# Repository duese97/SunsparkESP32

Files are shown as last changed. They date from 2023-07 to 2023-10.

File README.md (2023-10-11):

# SunsparkESP32
A new ESP32 hardware platform for low power applications.

This PCB utilizes a small solar cell in order to harvest energy and store it in a supercapacitor.

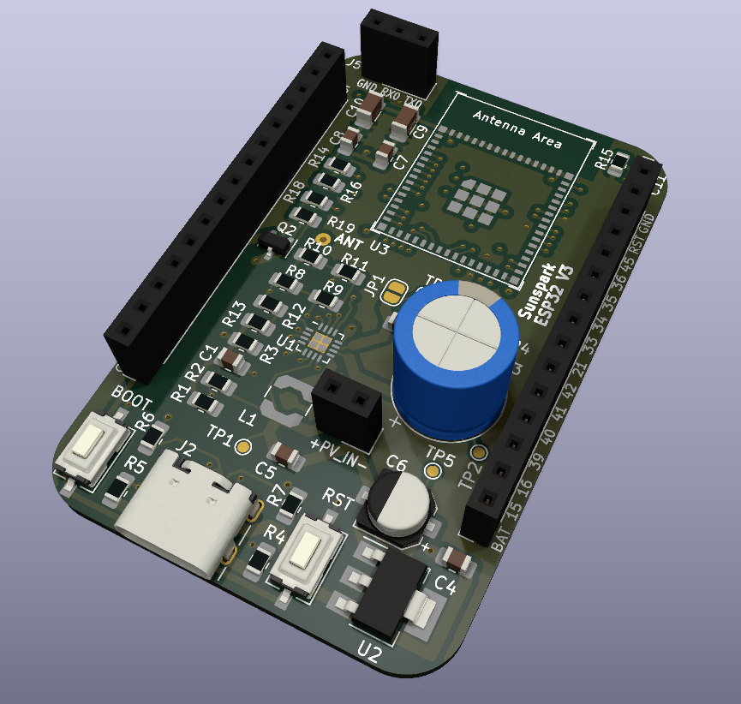
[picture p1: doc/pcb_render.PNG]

*The rendered PCB for the SunsparkESP32*

## Features
1. ESP32 S2 Mini module with a single core MCU: Most projects utilize one core anyway or don't benefit much form a second one. So no current is wasted by idling unnecessary.
2. Native USB support: Converter for RS232 can be connected externally. Many USB to RS232 transceivers have a high quiescent consumption. They are mostly needed for debugging, in order to show data to a console. Flashing the chip also works via the USB bootloader (and is also faster).
3. Integrated open drain MOSFET: Control high power external peripherals and turn them off when not needed.
4. VBUS from USB utilized automatically as backup supply, so debugging does not drain the supercap.
5. Optional RF95/96/97/98 LoRa module can be added (library used: https://github.com/sandeepmistry/arduino-LoRa/tree/master)

## Application example
I included some FW which realizes a simple WiFI weather station with a common BME280. However it can be easily altered to work with different or more sensors as well. It works well enough that it can sustain it's 10min scheduled data delivery indoors, in my living room.

Shutting down/entering deepsleep immediately after sending the UDP packet seems not to work (underlying RTOS or network stack takes some time). Thus I additionally set up the the UDP Server in a way that it sends a small sting back, upon receiving data.
The provided code does not utilizes this any further, but it could be a nice way for a two way communication. The ESP32 will run 1s at most, an then enter sleep again:
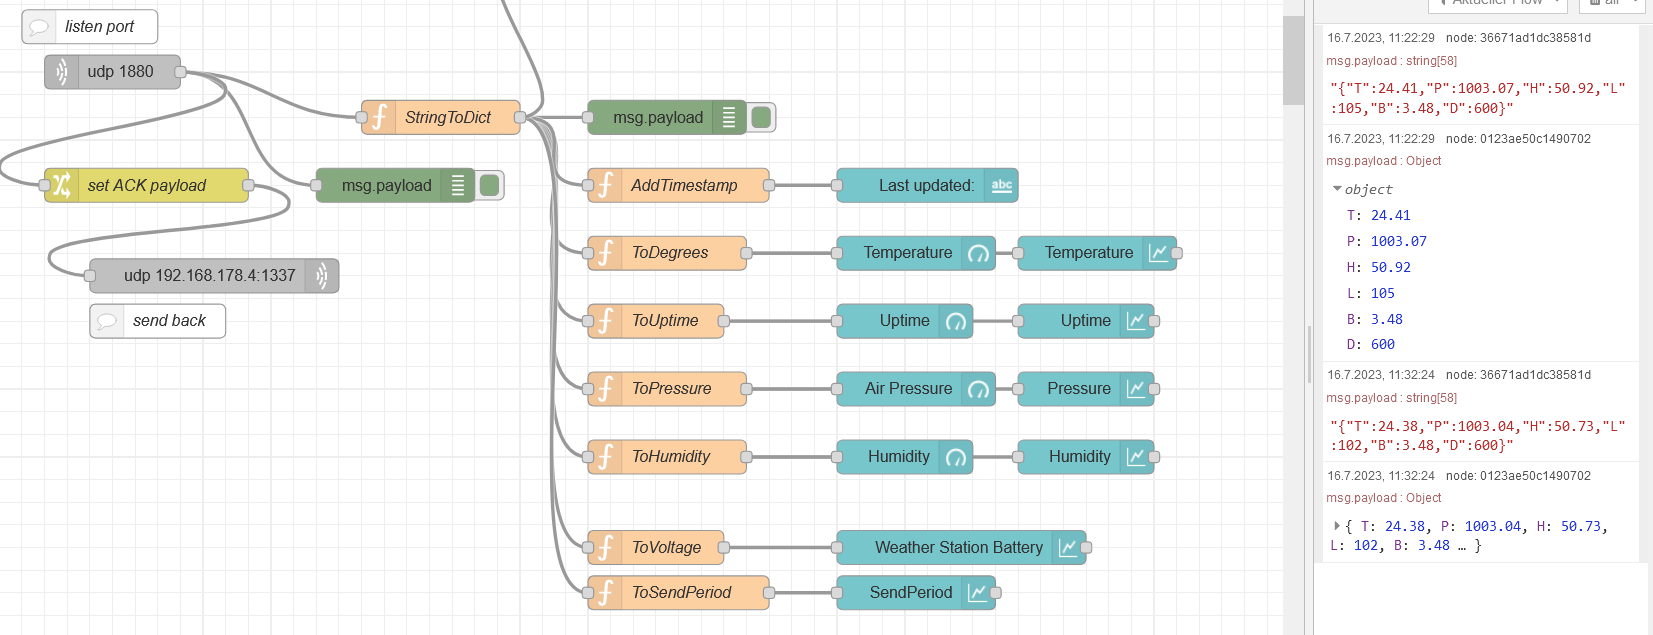
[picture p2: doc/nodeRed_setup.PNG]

*Example flow for parsing incoming results in Node RED*

There is also some small logic, which handles a depletion (or charging) of the supercap by altering the deepsleep period.

I found it helpful to include a runtime checked "debug mode". Tieing a GPIO to high, and to "artificially" shorten the sleep time, so I can debug more easily. Setting it to low put it back into "normal" mode and also disabled some UART prints.

Note: Altered Adafruit_BME280::begin so that is does NOT call
Adafruit_BME280::init upon each wakeup of device -> sensor is permanently
supplied with VCC and does not need a lengthy re-init each time

## Requirements for external components/assembly
1. The open circuit voltage of the solar cell should not exceed 3.3V. Recommended is 1.5V @ 0.65W
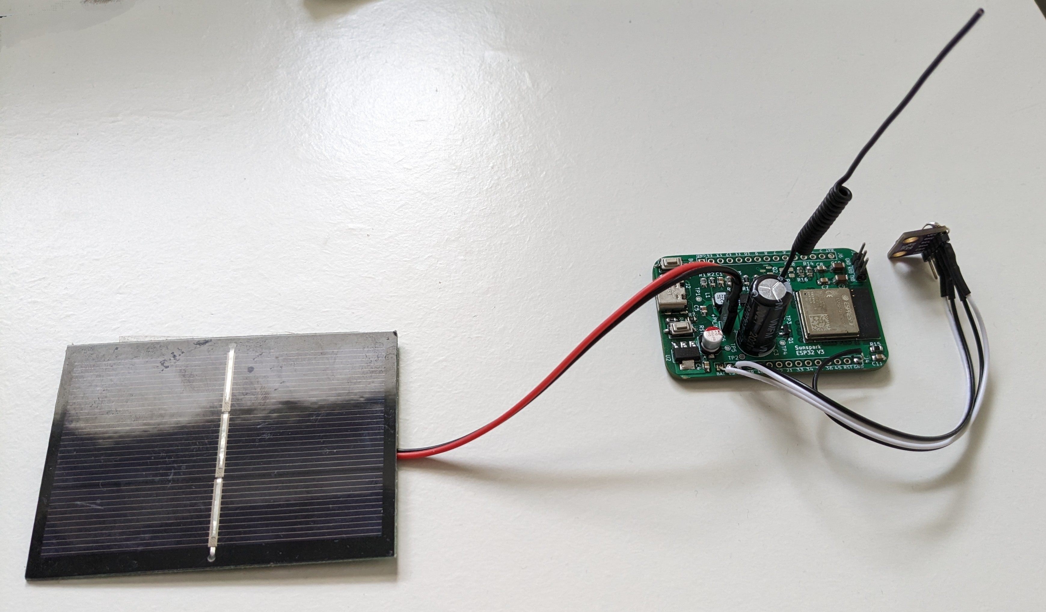
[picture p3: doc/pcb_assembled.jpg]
2. Make sure to protect the PCB when using it outdoors. Especially the Mega Ohm resistors are sensitive to water. I use clear nail polish for this. 
*The PCB with the solar cell and a BME280 soldered to it. The 433MHz antenna for the RF96 is also visible.*
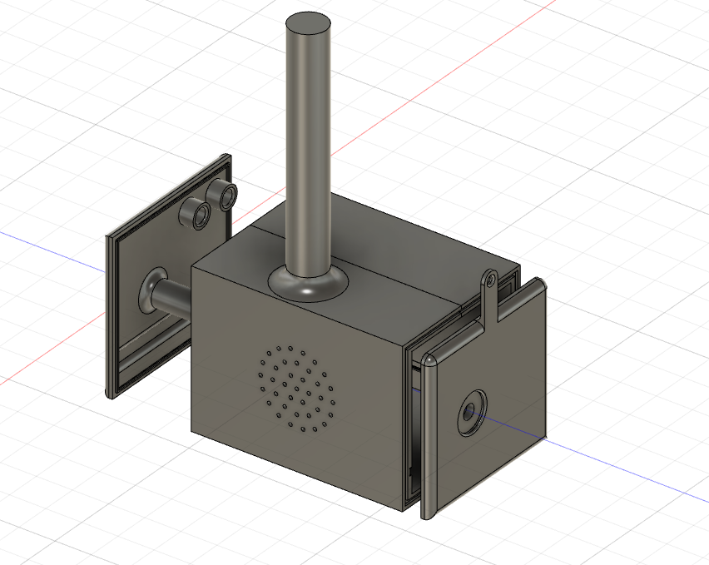
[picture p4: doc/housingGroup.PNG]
3. Mechanically a 3D printed assembly can accommodate the circuit shown above. The solar cell can be glued to the housing. 
*The 3D printed enclosure.*

## Errata
### V3 board
1. Current consumption with LoRa module seems too high in idle (when in deepsleep)
2. Still issues with occasional brownouts, when using WiFi
### V2 board
1. ~~USB VCOM for bootloader not working -> GND from USB and GND1 from ESP differ?~~ Forgot to compile with USB CDC enabled
2. BOOT button only working when Supercap is sufficiently charged?
3. Linear 3V3 regulator instantly produced some magic smoke upon connecting VBUS from USB :) There seem to be different pinouts for the same footprint of the same IC!
4. VREF for ADP5090 is too low and not constant

## Charging estimation
### V2 board
In direct sunlight: ~40mA, in the shade with average cloudiness: 2mA.

## Current consumption estimation
General testing consists of the board being flashed with a WiFi UDP client. It posts ~50B of data every 10 minutes to a Node RED UDP server. Static IP config is utilized, to avoid waiting for the DHCP.
Active time is about 0.5s, while sleeping the rest of the time.
The challenge are the short current bursts when the WiFi peripheral is actively used:
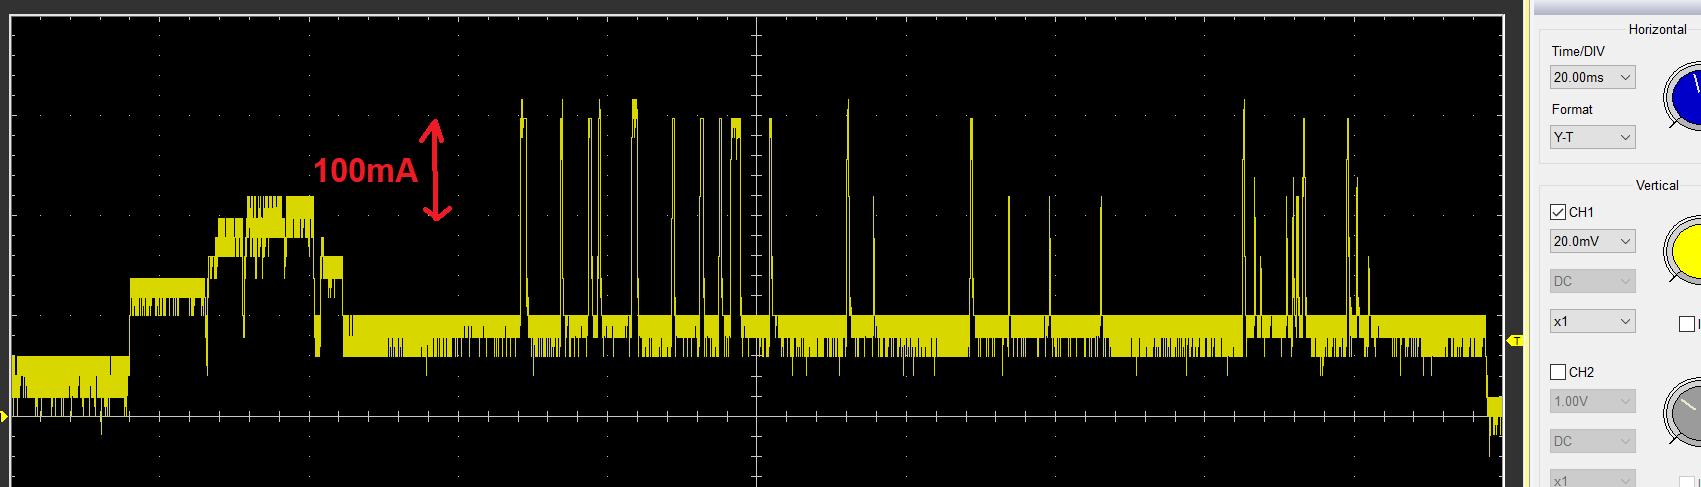
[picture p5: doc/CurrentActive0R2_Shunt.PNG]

*Scoped voltage over a shunt during board activity*

Values for estimating discharging of capacitor:
### V2 board
Active: 45mA; Sleep: 10µA; 50µA average

Improvements mostly due to better ceramic caps (?)
### V1 board
Active: 30mA; Sleep: 90µA; 115µA average

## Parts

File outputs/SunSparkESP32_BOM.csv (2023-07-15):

Id | Designator | Footprint | Quantity | Designation | Manufacturer | Comment | Mouser #
1 | C5,C2 | C_0805_2012Metric_Pad1.18x1.45mm_HandSolder | 2 | 4µ7 | C2012X5R1C475M085AB | low ESR, Generic 0805 | 810-C2012X5R1C475M0B
2 | L1 | L_Coilcraft_LPS4018 | 1 | 22µ | LPS4018-223MRC |  | 994-LPS4018-223MRC
3 | U1 | LFCSP-16-1EP_3x3mm_P0.5mm_EP1.7x1.7mm | 1 | ADP5090ACP | ADP5090ACPZ-2-R7 |  | 584-ADP5090ACPZ-2-R7
4 | R18,R19,R3,R14,R16 | R_0805_2012Metric_Pad1.20x1.40mm_HandSolder | 5 | 20k |  | Generic 0805
5 | C4,C1 | C_0805_2012Metric_Pad1.18x1.45mm_HandSolder | 2 | 10n | C0805X103K2RAC3316 | low ESR and leakage type | 80-C0805X103K2R3316
6 | R6,R7 | R_0805_2012Metric_Pad1.20x1.40mm_HandSolder | 2 | 22R |  | Generic 0805
7 | R12,R11 | R_0805_2012Metric_Pad1.20x1.40mm_HandSolder | 2 | 3.92M |  | Generic 0805
8 | C6 | CP_Elec_5x3 | 1 | 47µ | 865080242004 |  | 710-865080242004
9 | TP5,TP3,TP4,TP2,TP1 | TestPoint_Pad_D1.0mm | 5 | TestPoint
10 | R9 | R_0805_2012Metric_Pad1.20x1.40mm_HandSolder | 1 | 5.23M |  | Generic 0805
11 | C8,C11,C7 | C_0805_2012Metric_Pad1.18x1.45mm_HandSolder | 3 | 100n |  | Generic 0805
12 | R8 | R_0805_2012Metric_Pad1.20x1.40mm_HandSolder | 1 | 4.87M |  | Generic 0805
13 | U3 | ESP32-S2-MINI-1 | 1 | ESP32-S2-MINI-1 | ESP32-S2-MINI-1-N4 |  | 356-ESP32-S2-MINI-1
14 | SW2,SW1 | SW_Tactile_SPST_NO_Straight_CK_PTS636Sx25SMTRLFS | 2 | SW_Push | PTS636 SM25J SMTR LFS |  | 611-PTS636SM25JSMTRL
15 | R15 | R_0805_2012Metric_Pad1.20x1.40mm_HandSolder | 1 | 10k |  | Generic 0805
16 | J2 | USB_C_Receptacle_GCT_USB4105-xx-A_16P_TopMnt_Horizontal | 1 | USB_C_Receptacle_USB2.0 | USB4105-GF-A |  | 640-USB4105-GF-A
17 | J5 | PinSocket_1x03_P2.54mm_Vertical | 1 | Conn_01x03_Pin |  | generic pin header
18 | R5,R4 | R_0805_2012Metric_Pad1.20x1.40mm_HandSolder | 2 | 5.1k |  | Generic 0805
19 | Q1,Q2 | SOT-23 | 2 | IRLML6244TRPBF | IRLML6244TRPBF |  | 942-IRLML6244TRPBF
20 | C9,C10 | C_1206_3216Metric | 2 | 22µ | C3216JB1C226M160AB | low ESR | 810-C3216JB1C226M16B
21 | JP1,JP2 | SolderJumper-2_P1.3mm_Open_RoundedPad1.0x1.5mm | 2 | SolderJumper_2_Open
22 | R1 | R_0805_2012Metric_Pad1.20x1.40mm_HandSolder | 1 | 13M |  | Generic 0805
23 | J1 | PinSocket_1x02_P2.54mm_Vertical | 1 | Conn_01x02_Pin |  | generic pin header
24 | R10,R13 | R_0805_2012Metric_Pad1.20x1.40mm_HandSolder | 2 | 6.04M |  | Generic 0805
25 | J4,J6 | PinSocket_1x15_P2.54mm_Vertical | 2 | Conn_01x15_Pin |  | generic pin header
26 | U2 | SOT-223-3_TabPin2 | 1 | AMS1117-3.3 | TLV1117LV33DCYT | Watch for variants with different pinning, not any generic 1117 will work!!! | 595-TLV1117LV33DCYT
27 | C3 | CP_Radial_D10.0mm_P5.00mm | 1 | 50F | VMF506M3R8 | Must tolerate 3.6V, 30..50F is ok | 598-VMF506M3R8
28 | R2 | R_0805_2012Metric_Pad1.20x1.40mm_HandSolder | 1 | 6.34M |  | Generic 0805
29 | J7 | TestPoint_THTPad_D1.5mm_Drill0.7mm | 1 | Conn_01x01_Pin |  | generic pin header
30 | U4 | HOPERF_RFM9XW_SMD | 1 | RFM96W-433S2

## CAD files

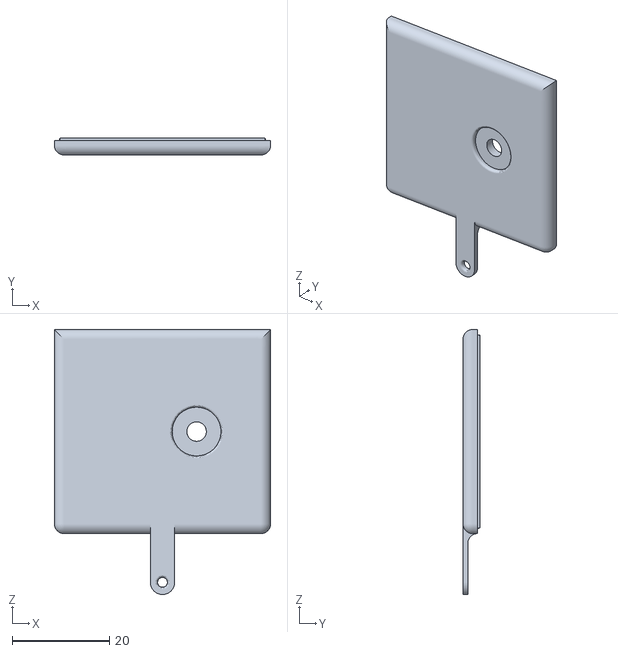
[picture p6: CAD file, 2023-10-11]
mechanical/lid_small.stl
44.4 x 3.50 x 54.4

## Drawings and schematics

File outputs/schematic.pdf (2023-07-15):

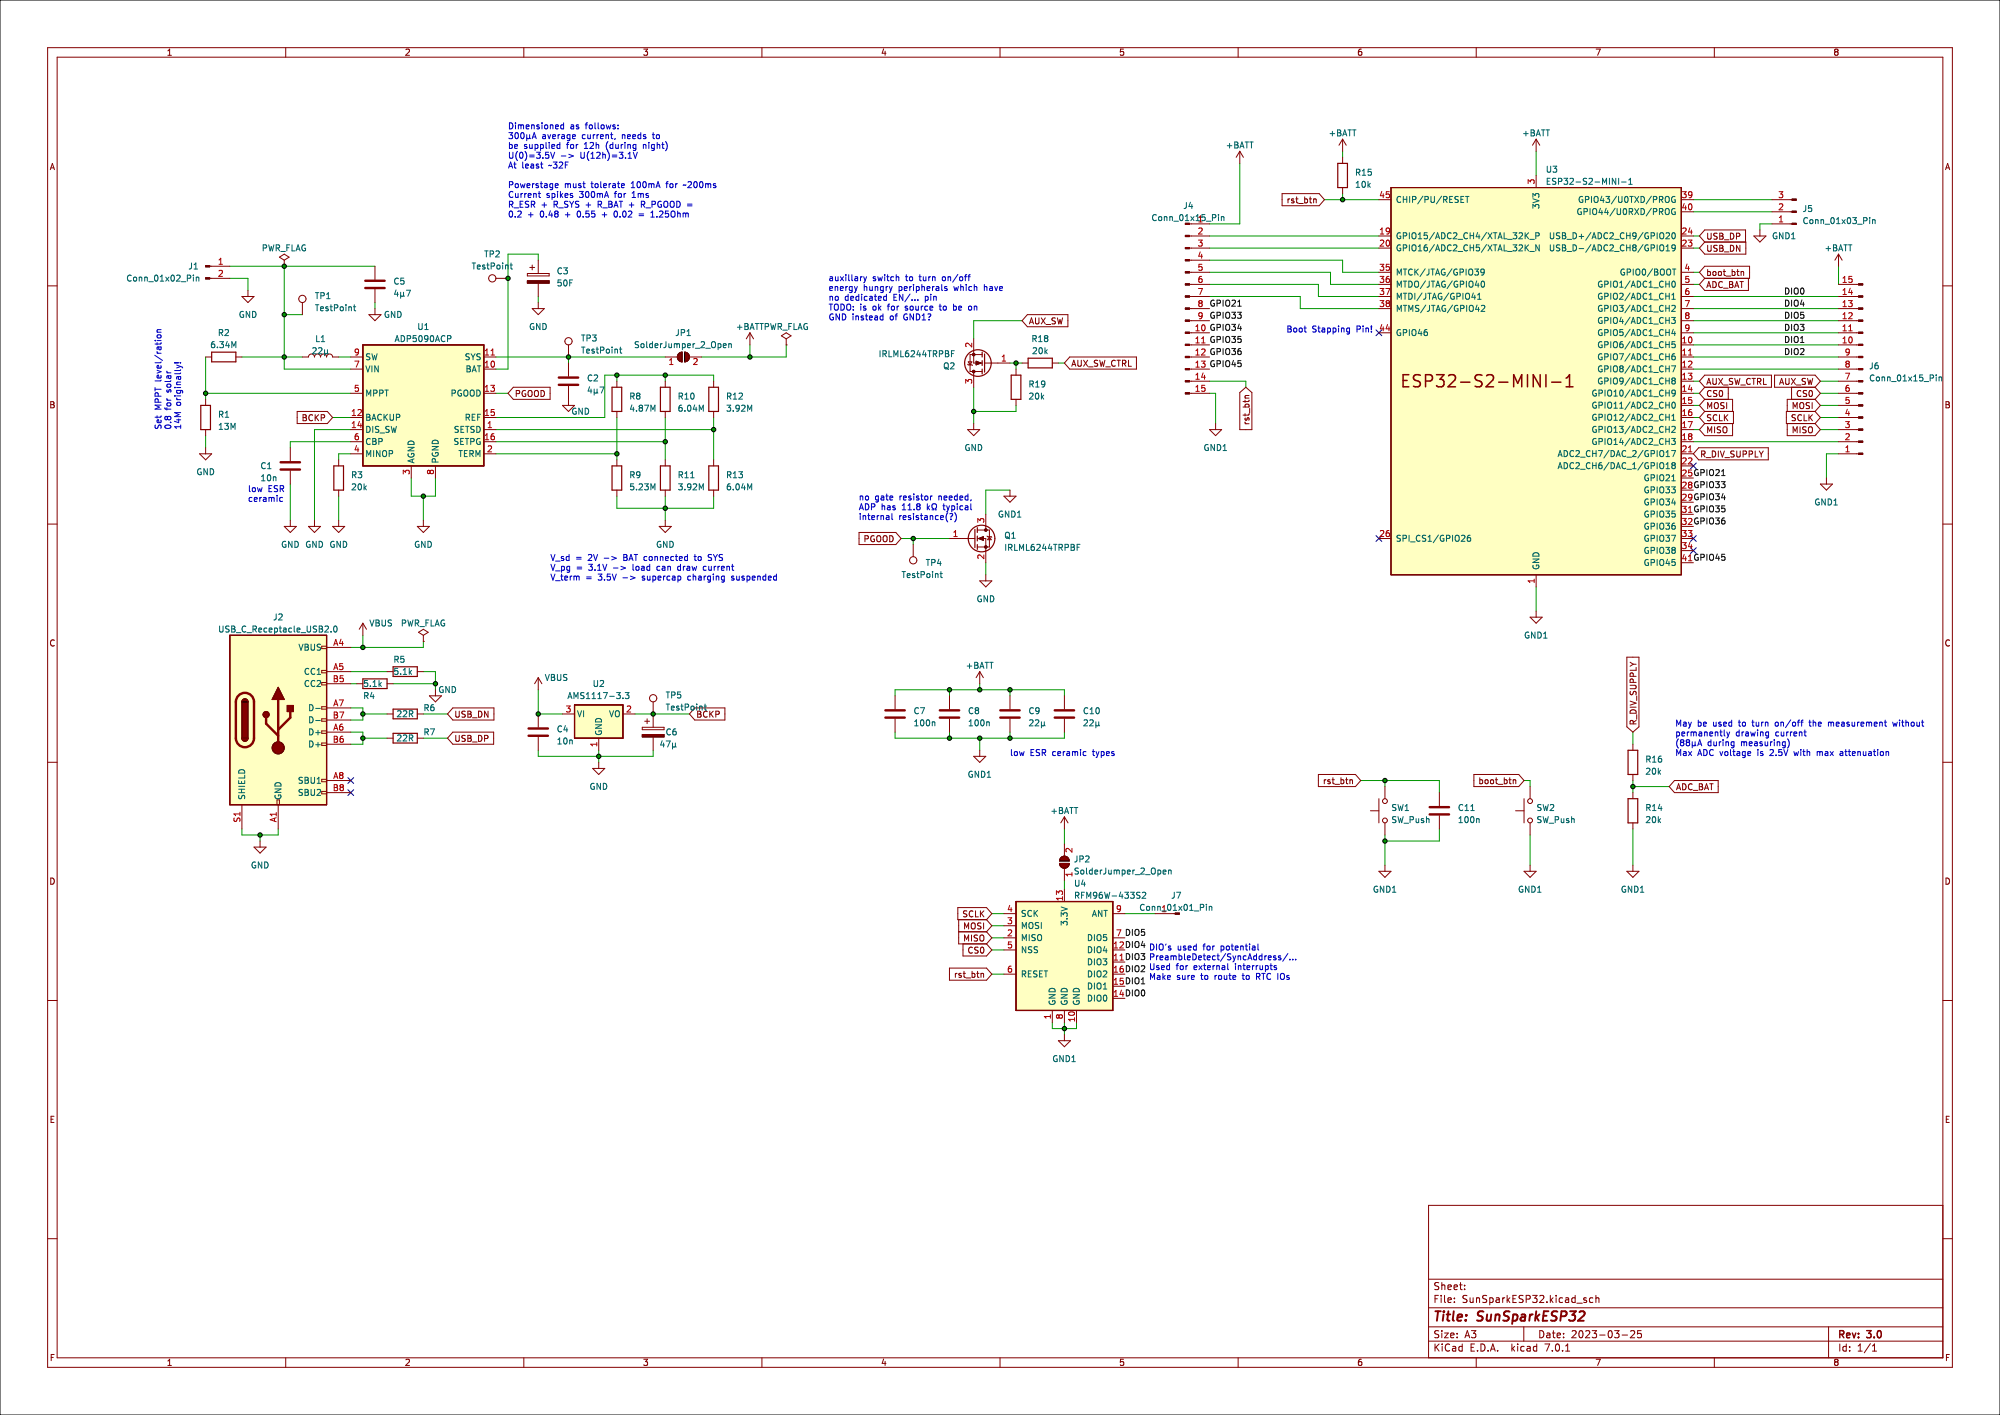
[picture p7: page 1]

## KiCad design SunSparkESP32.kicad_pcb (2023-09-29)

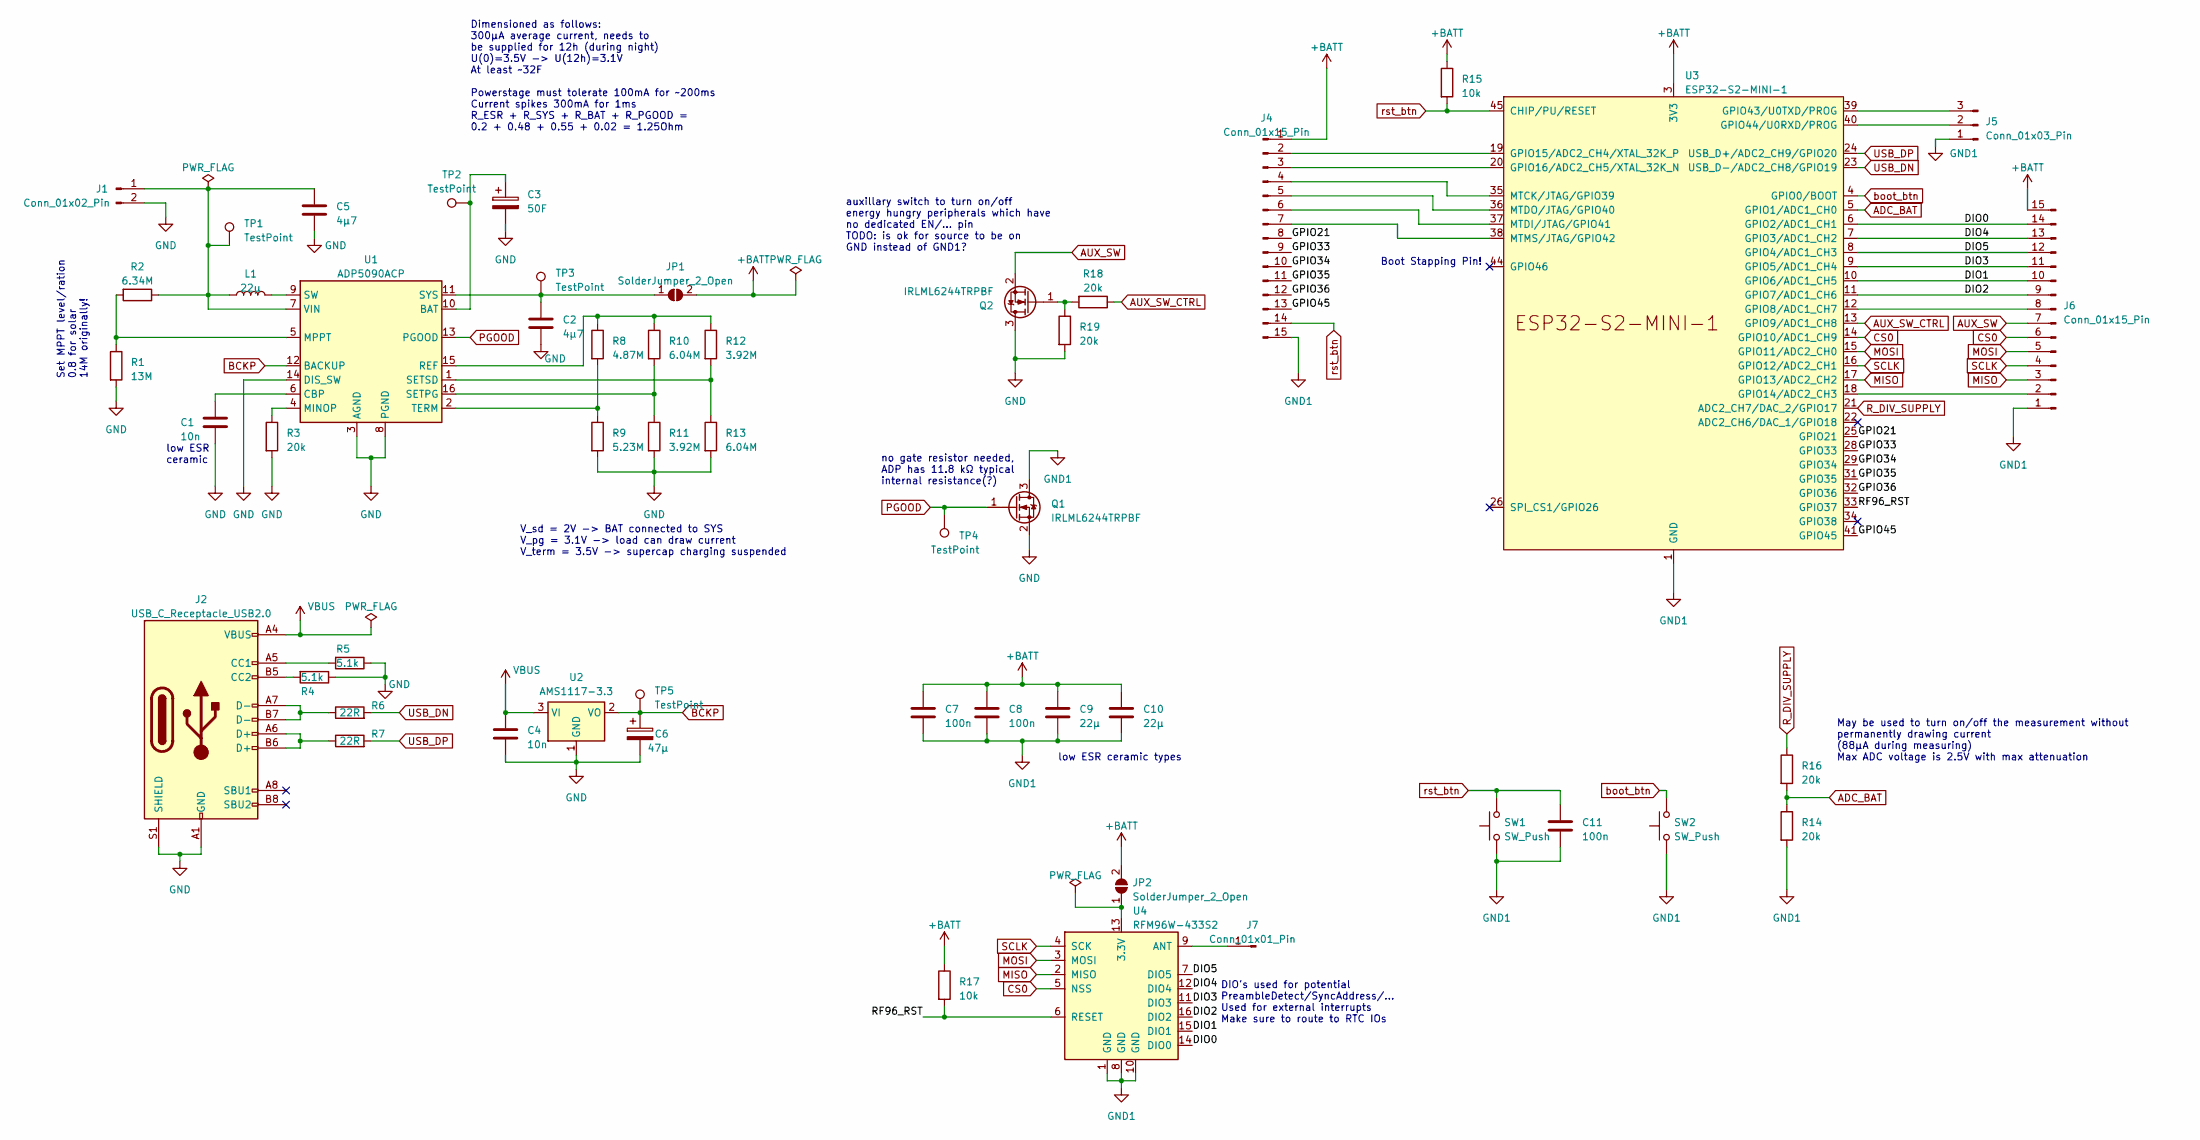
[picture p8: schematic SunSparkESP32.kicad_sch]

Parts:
C1, C4: 10n; C_0805_2012Metric_Pad1.18x1.45mm_HandSolder
C2, C5: 4µ7; C_0805_2012Metric_Pad1.18x1.45mm_HandSolder
C3: 50F; CP_Radial_D10.0mm_P5.00mm
C6: 47µ; CP_Elec_5x3
C7, C8, C11: 100n; C_0805_2012Metric_Pad1.18x1.45mm_HandSolder
C9, C10: 22µ; C_1206_3216Metric
J1: Conn_01x02_Pin; PinSocket_1x02_P2.54mm_Vertical
J2: USB_C_Receptacle_USB2.0; USB_C_Receptacle_GCT_USB4105-xx-A_16P_TopMnt_Horizontal
J4, J6: Conn_01x15_Pin; PinSocket_1x15_P2.54mm_Vertical
J5: Conn_01x03_Pin; PinSocket_1x03_P2.54mm_Vertical
J7: Conn_01x01_Pin; TestPoint_THTPad_D1.5mm_Drill0.7mm
JP1, JP2: SolderJumper_2_Open; SolderJumper-2_P1.3mm_Open_RoundedPad1.0x1.5mm
L1: 22µ; L_Coilcraft_LPS4018
Q1, Q2: IRLML6244TRPBF; SOT-23
R1: 13M; R_0805_2012Metric_Pad1.20x1.40mm_HandSolder
R2: 6.34M; R_0805_2012Metric_Pad1.20x1.40mm_HandSolder
R3, R14, R16, R18, R19: 20k; R_0805_2012Metric_Pad1.20x1.40mm_HandSolder
R4, R5: 5.1k; R_0805_2012Metric_Pad1.20x1.40mm_HandSolder
R6, R7: 22R; R_0805_2012Metric_Pad1.20x1.40mm_HandSolder
R8: 4.87M; R_0805_2012Metric_Pad1.20x1.40mm_HandSolder
R9: 5.23M; R_0805_2012Metric_Pad1.20x1.40mm_HandSolder
R10, R13: 6.04M; R_0805_2012Metric_Pad1.20x1.40mm_HandSolder
R11, R12: 3.92M; R_0805_2012Metric_Pad1.20x1.40mm_HandSolder
R15, R17: 10k; R_0805_2012Metric_Pad1.20x1.40mm_HandSolder
SW1, SW2: SW_Push; SW_Tactile_SPST_NO_Straight_CK_PTS636Sx25SMTRLFS
TP1, TP2, TP3, TP4, TP5: TestPoint; TestPoint_Pad_D1.0mm
U1: ADP5090ACP; LFCSP-16-1EP_3x3mm_P0.5mm_EP1.7x1.7mm
U2: AMS1117-3.3; SOT-223-3_TabPin2
U3: ESP32-S2-MINI-1
U4: RFM96W-433S2; HOPERF_RFM9XW_SMD

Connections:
+BATT: C7.1, C8.1, C9.1, C10.1, J4.1, J6.15, JP1.2 (B), JP2.2 (B), R15.1, R17.1, U3.3 (3V3)
/DIO0: J6.14, U3.6 (GPIO2/ADC1_CH1), U4.14 (DIO0)
/DIO1: J6.10, U3.10 (GPIO6/ADC1_CH5), U4.15 (DIO1)
/DIO2: J6.9, U3.11 (GPIO7/ADC1_CH6), U4.16 (DIO2)
/DIO3: J6.11, U3.9 (GPIO5/ADC1_CH4), U4.11 (DIO3)
/DIO4: J6.13, U3.7 (GPIO3/ADC1_CH2), U4.12 (DIO4)
/DIO5: J6.12, U3.8 (GPIO4/ADC1_CH3), U4.7 (DIO5)
/GPIO21: J4.8, U3.25 (GPIO21)
/GPIO33: J4.9, U3.28 (GPIO33)
/GPIO34: J4.10, U3.29 (GPIO34)
/GPIO35: J4.11, U3.31 (GPIO35)
/GPIO36: J4.12, U3.32 (GPIO36)
/GPIO45: J4.13, U3.41 (GPIO45)
/RF96_RST: R17.2, U3.33 (GPIO37), U4.6 (RESET)
ADC_BAT: R14.1, R16.2, U3.5 (GPIO1/ADC1_CH0)
AUX_SW: J6.7, Q2.2 (S)
AUX_SW_CTRL: R18.1, U3.13 (GPIO9/ADC1_CH8)
BCKP: C6.1, TP5.1, U1.12 (BACKUP), U2.2 (VO)
CS0: J6.6, U3.14 (GPIO10/ADC1_CH9), U4.5 (NSS)
GND: C1.2, C2.2, C3.2, C4.2, C5.2, C6.2, J1.2, J2.A1 (GND), J2.A12 (GND), J2.B1 (GND), J2.B12 (GND), J2.S1 (SHIELD), Q1.2 (S), Q2.3 (D), R1.2, R3.2, R4.1, R5.1, R9.2, R11.2, R13.2, R19.2, U1.3 (AGND), U1.8 (PGND), U1.14 (DIS_SW), U1.17 (AGND), U2.1 (GND)
GND1: C7.2, C8.2, C9.2, C10.2, C11.2, J4.15, J5.1, J6.1, Q1.3 (D), R14.2, SW1.1, SW2.1, U3.1 (GND), U3.2 (GND), U3.30 (GND), U3.42 (GND), U3.43 (GND), U3.46 (GND), U3.47 (GND), U3.48 (GND), U3.49 (GND), U3.50 (GND), U3.51 (GND), U3.52 (GND), U3.53 (GND), U3.54 (GND), U3.55 (GND), U3.56 (GND), U3.57 (GND), U3.58 (GND), U3.59 (GND), U3.60 (GND), U3.61 (GND), U3.62 (GND), U3.63 (GND), U3.64 (GND), U3.65 (GND), U4.1 (GND), U4.8 (GND), U4.10 (GND)
MISO: J6.3, U3.17 (GPIO13/ADC2_CH2), U4.2 (MISO)
MOSI: J6.5, U3.15 (GPIO11/ADC2_CH0), U4.3 (MOSI)
unnamed: C5.1, J1.1, L1.1, R2.1, TP1.1, U1.7 (VIN)
unnamed: J2.A5 (CC1), R5.2
unnamed: J2.B5 (CC2), R4.2
unnamed: J2.A6 (D+), J2.B6 (D+), R7.1
unnamed: J2.A7 (D-), J2.B7 (D-), R6.1
unnamed: J4.2, U3.19 (GPIO15/ADC2_CH4/XTAL_32K_P)
unnamed: J4.3, U3.20 (GPIO16/ADC2_CH5/XTAL_32K_N)
unnamed: J4.4, U3.35 (MTCK/JTAG/GPIO39)
unnamed: J4.5, U3.36 (MTDO/JTAG/GPIO40)
unnamed: J4.6, U3.37 (MTDI/JTAG/GPIO41)
unnamed: J4.7, U3.38 (MTMS/JTAG/GPIO42)
unnamed: J5.2, U3.40 (GPIO44/U0RXD/PROG)
unnamed: J5.3, U3.39 (GPIO43/U0TXD/PROG)
unnamed: J6.2, U3.18 (GPIO14/ADC2_CH3)
unnamed: J6.8, U3.12 (GPIO8/ADC1_CH7)
unnamed: J7.1, U4.9 (ANT)
unnamed: C2.1, JP1.1 (A), TP3.1, U1.11 (SYS)
unnamed: JP2.1 (A), U4.13 (3.3V)
unnamed: Q2.1 (G), R18.2, R19.1
unnamed: C3.1, TP2.1, U1.10 (BAT)
unnamed: C1.1, U1.6 (CBP)
unnamed: R3.1, U1.4 (MINOP)
unnamed: R1.1, R2.2, U1.5 (MPPT)
unnamed: R8.1, R10.1, R12.1, U1.15 (REF)
unnamed: R10.2, R11.1, U1.16 (SETPG)
unnamed: R12.2, R13.1, U1.1 (SETSD)
unnamed: L1.2, U1.9 (SW)
unnamed: R8.2, R9.1, U1.2 (TERM)
PGOOD: Q1.1 (G), TP4.1, U1.13 (PGOOD)
R_DIV_SUPPLY: R16.1, U3.21 (ADC2_CH7/DAC_2/GPIO17)
SCLK: J6.4, U3.16 (GPIO12/ADC2_CH1), U4.4 (SCK)
USB_DN: R6.2, U3.23 (USB_D-/ADC2_CH8/GPIO19)
USB_DP: R7.2, U3.24 (USB_D+/ADC2_CH9/GPIO20)
VBUS: C4.1, J2.A4 (VBUS), J2.A9 (VBUS), J2.B4 (VBUS), J2.B9 (VBUS), U2.3 (VI)
boot_btn: SW2.2, U3.4 (GPIO0/BOOT)
rst_btn: C11.1, J4.14, R15.2, SW1.2, U3.45 (CHIP/PU/RESET)

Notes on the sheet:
Set MPPT level/ration 0.8 for solar 14M originally!
no gate resistor needed, ADP has 11.8 kΩ typical internal resistance(?)
low ESR ceramic types
Dimensioned as follows: 300µA average current, needs to be supplied for 12h (during night) U(0)=3.5V -> U(12h)=3.1V At least ~32F Powerstage must tolerate 100mA for ~200ms Current spikes 300mA for 1ms R_ESR + R_SYS + R_BAT + R_PGOOD = 0.2 + 0.48 + 0.55 + 0.02 = 1.25Ohm
low ESR ceramic
May be used to turn on/off the measurement without permanently drawing current (88µA during measuring) Max ADC voltage is 2.5V with max attenuation
V_sd = 2V -> BAT connected to SYS V_pg = 3.1V -> load can draw current V_term = 3.5V -> supercap charging suspended
auxillary switch to turn on/off energy hungry peripherals which have no dedicated EN/... pin TODO: is ok for source to be on GND instead of GND1?
DIO's used for potential PreambleDetect/SyncAddress/... Used for external interrupts Make sure to route to RTC IOs
Boot Stapping Pin!

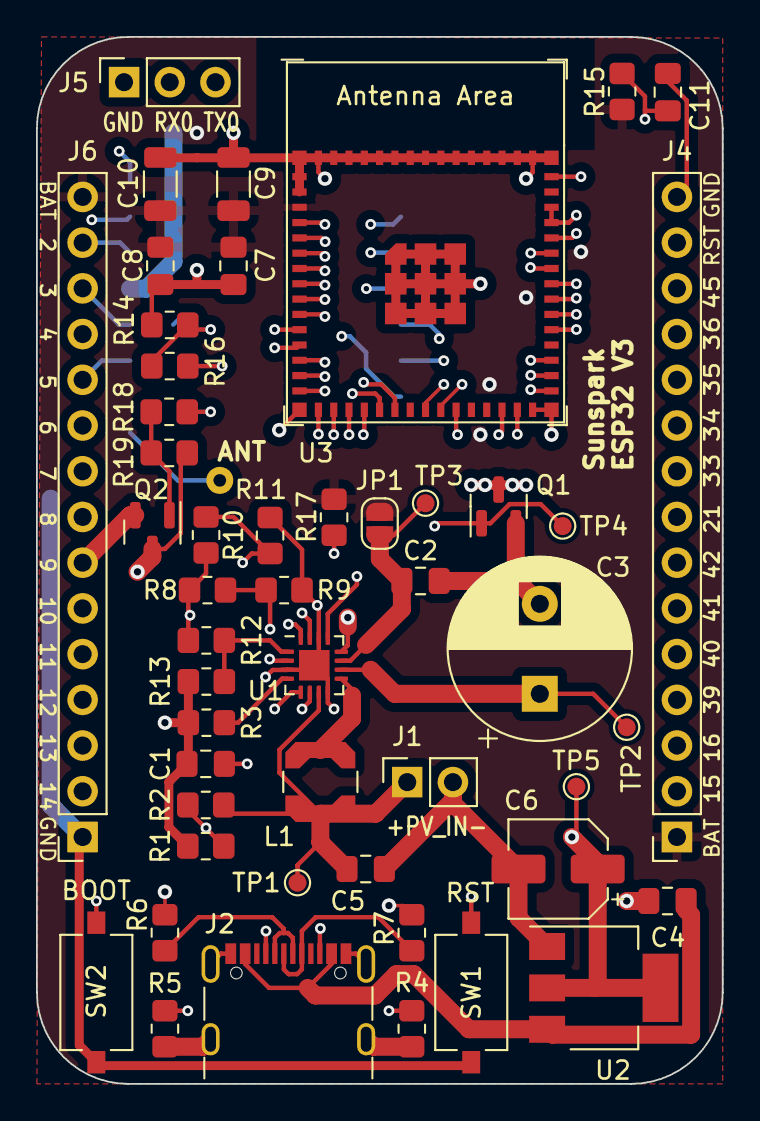
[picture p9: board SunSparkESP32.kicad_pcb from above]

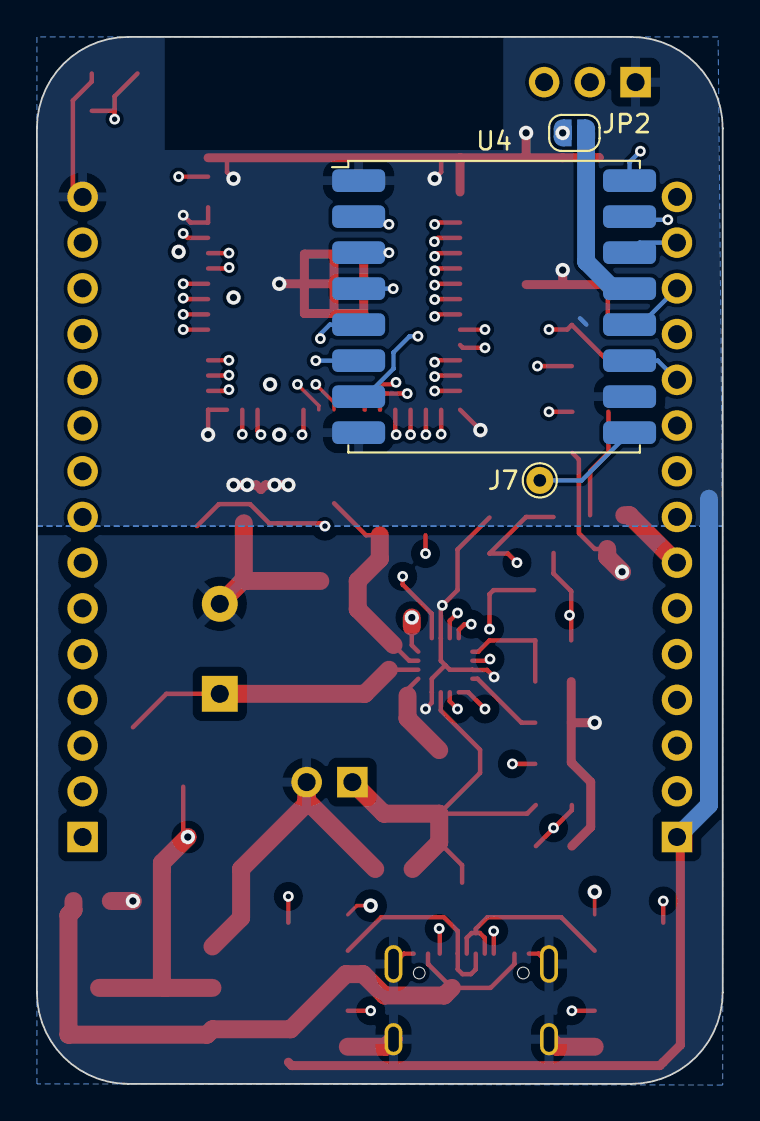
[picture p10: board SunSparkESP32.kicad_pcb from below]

Board: 4 copper layers, 38.1 x 58.2 mm, 52 parts (3 on the bottom side), 59 nets.

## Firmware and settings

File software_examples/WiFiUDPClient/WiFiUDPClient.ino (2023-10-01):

#include <Arduino.h>

#include <HardwareSerial.h>

#include <Wire.h>

/* SENSOR SPECIFIC INCLUDES */
#include <SPI.h>
#include <Adafruit_Sensor.h>
#include <Adafruit_BME280.h>

#include "esp32s2/rom/rtc.h"  // for reset reason etc.
#include "esp32/clk.h"

#define WIFI_USED 0

#if WIFI_USED == 1
#include <WiFi.h>
#include <WiFiUdp.h>
#else
#include <SPI.h>
#include <LoRa.h>
#endif  // WIFI_USED


/* Pins where UART pin header is routed */
#define RXD0 40
#define TXD0 39

#define DEBUG_PIN 40

#define RF96_DIO0 2
#define RF96_CS 10
#define RF96_MOSI 11
#define RF96_CLK 12
#define RF96_MISO 13

/* Conversion factors for time related stuff */
#define SECONDS_PER_MIN 60
#define MIN_PER_HOUR 60
#define uS_TO_S_FACTOR 1000000
#define mS_TO_S_FACTOR 1000

/* Constants which influence wakup and sleep behaviour */
#define MIN_SLEEP_TIME SECONDS_PER_MIN * 10               // Time ESP32 will go to sleep (in seconds)
#define MAX_SLEEP_TIME SECONDS_PER_MIN* MIN_PER_HOUR * 8  // sleep third a day at max
#define DEBUG_SLEEP_TIME SECONDS_PER_MIN                  // for quickly debugging
#define NETWORK_WAIT_MS 1                                 // task delay in polling loop
#define MAX_WAKEUP_MS 1000                                // total amount of milli seconds device operation can be done

/* Supercap related */
#define CAP_FULL_LVL 3.4    // if this or higher is read, then supercap is definetly full
#define CAP_NORMAL_LVL 3.3  // voltage threshold above which normal operation can take place
#define PIN_R_DIV 17        // pin which powers voltage divider for ADC
#define PIN_ADC 1           // where midpoint of divider is connected

// only need to use (and waste) ebergy when debugging
#define custom_println(...) \
  if (use_debug_mode) { \
    snprintf(print_buffer, sizeof(print_buffer), __VA_ARGS__); \
    customSerial.println(print_buffer); \
  }

/* values for statemachine */
enum {
  STATE_SENSOR_INIT,   // optional: in case sensor feature sleeping state as well, init can be skipped most of times
  STATE_SENSOR_READ,   // optional: do sensor readings before starting wifi transceiver!
  STATE_NETWORK_INIT,  // setting up wifi
  STATE_NETWORK_WAIT,  // waiting for intial connect
  STATE_SEND,          // transmitting data
  STATE_WAIT_ACK,      // optional: receive data back
  STATE_SLEEP,         // prepare sleeping
};

#if WIFI_USED == 1
/* Network related constants */
const char * networkName    = "your_ssid"; // name of wifi
const char * networkPswd    = "your_password";          // password of wifi

// set these up in router, so that ít conflicts with nothing else
const char* device_ip = "192.168.178.4";
const char* device_subnet = "255.255.255.0";
const char* device_gateway = "192.168.178.1";

const char* udpAddress = "192.168.178.33";  // IP address to send UDP data to
const int udpListenPort = 1337;             // on which port to listen
const int udpSendPort = 1880;               // to which port to send to

/* Network variables */
WiFiUDP Udp;  //The Udp library class
#endif        // WIFI_USED


/* State machine */
uint32_t millis_start, active_time;
RTC_DATA_ATTR uint32_t last_active;               // to measure entire cycle, can be outputted upon next connect
RTC_DATA_ATTR float last_delta_v;                 // to measure entire cycle, can be outputted upon next connect
volatile uint8_t curr_state = STATE_SENSOR_READ;  // default state, init only set if
bool use_debug_mode = false;                      // flag for easily debugging code via prints :)
bool lora_active = false;

float supercap_voltage;                                      // supercap voltage in V
RTC_DATA_ATTR uint32_t timeToSleepSeconds = MIN_SLEEP_TIME;  // sleep time, stored in RTC RAM to also take past operation into account


/* ADD SENSOR SPECIFIC CODE HERE */
#define BME_WAIT_MS 10
#define I2C_SDA 15
#define I2C_SCL 16

RTC_DATA_ATTR Adafruit_BME280 bme;  // I2C
float temp, humi, press;

/* Print buffer for easily formatting */
char print_buffer[256];

HardwareSerial customSerial(0);

#if WIFI_USED == 1
/* Wifi callbacks */
void connectToWiFi(const char* ssid, const char* pwd) {
  custom_println("Connecting to WiFi network: %s", ssid);

  // delete old config
  WiFi.disconnect(true);
  //register event handler
  WiFi.onEvent(WiFiEvent);

  // setup static config
  IPAddress localIP, gateway, subnet;
  localIP.fromString(device_ip);
  gateway.fromString(device_gateway);
  subnet.fromString(device_subnet);

  WiFi.config(localIP, gateway, subnet);

  //Initiate connection
  WiFi.begin(ssid, pwd);

  custom_println("Waiting for WIFI connection...");
}

//wifi event handler
void WiFiEvent(WiFiEvent_t event) {
  switch (event) {
    case ARDUINO_EVENT_WIFI_STA_GOT_IP:  //When connected set
      custom_println("WiFi connected! IP address: %s", WiFi.localIP().toString().c_str());

      //initializes the UDP state -> This initializes the transfer buffer
      Udp.begin(WiFi.localIP(), udpListenPort);
      curr_state = STATE_SEND;
      break;

    case ARDUINO_EVENT_WIFI_STA_DISCONNECTED:
      custom_println("WiFi lost connection");
      curr_state = STATE_NETWORK_WAIT;
      break;
    default:
      break;
  }
}
#endif

// wrapper enter deepsleep
static void enter_deepsleep(void) {
  custom_println("%s", "Entering sleep");
  last_active = active_time;
  uint64_t sleepUs = timeToSleepSeconds * uS_TO_S_FACTOR - active_time * mS_TO_S_FACTOR;

  // take delay due to active time into account, to compensate for runtime
  esp_sleep_enable_timer_wakeup(sleepUs);
  esp_sleep_pd_config(ESP_PD_DOMAIN_RTC_PERIPH, ESP_PD_OPTION_OFF);
  esp_deep_sleep_start();
}

static float measure_adc(void) {
  float value;

  pinMode(PIN_R_DIV, OUTPUT);  // use pin to briefly drive voltage divider
  digitalWrite(PIN_R_DIV, HIGH);

  analogSetAttenuation(ADC_11db);
  value = (analogReadMilliVolts(PIN_ADC) / 1000.0) * 2;  // read voltage, is double that what we read

  digitalWrite(PIN_R_DIV, LOW);  // reset output so no current is drawn anymore

  return value;
}

// determines next sleep period and stores it in RTC RAM
static void calc_next_sleep(void) {
  supercap_voltage = measure_adc();

  /* Logic to determine next wakeup, depending on supercap charge */
  if (use_debug_mode) {
    timeToSleepSeconds = DEBUG_SLEEP_TIME;
  } else if (supercap_voltage >= CAP_FULL_LVL) {
    // cap is full, no matter what previously happend, reset sleep period to min
    timeToSleepSeconds = MIN_SLEEP_TIME;
  } else if (supercap_voltage >= CAP_NORMAL_LVL) {
    // cap charge is recovering, half the used period
    timeToSleepSeconds /= 2;
    if (timeToSleepSeconds < MIN_SLEEP_TIME)  // watch out to not make it too small
    {
      timeToSleepSeconds = MIN_SLEEP_TIME;
    }
  } else if (timeToSleepSeconds < MAX_SLEEP_TIME) {
    // double sleep period to save more energy
    timeToSleepSeconds *= 2;
  } else  // we are already waiting with the maximum possible period
  {
    timeToSleepSeconds = MAX_SLEEP_TIME;  // make sure to reset it to a proper value
  }
  custom_println("Chose sleep period: %lds", timeToSleepSeconds);
}

void setup() {
  /* WiFI needs min 80MHz, don't need that much for LoRa */
#if WIFI_USED == 1
  setCpuFrequencyMhz(80E6);
#else
  setCpuFrequencyMhz(10E6);
#endif // WIFI_USED

  RESET_REASON reason = rtc_get_reset_reason(0);  // check why we woke up
  pinMode(DEBUG_PIN, INPUT_PULLDOWN);
  use_debug_mode = digitalRead(DEBUG_PIN);

  // Initialize hardware serial
  customSerial.begin(115200, SERIAL_8N1, RXD0, TXD0);
  custom_println("SunsparkESP32 start, reset reason: %d", reason);  // output reset reason

  switch (reason)  // depending on
  {
    case RTCWDT_BROWN_OUT_RESET:  // when brownout was active: don't continue, save energy
      enter_deepsleep();
      break;

    case POWERON_RESET:
      curr_state = STATE_SENSOR_INIT;

    default:  // will most ofen land here, rtc wakeup
      break;
  }

  calc_next_sleep();
  millis_start = millis();  // remember start of statemachine

  /* DO SENSOR SPECIFIC STUFF HERE */
  Wire.begin(I2C_SDA, I2C_SCL, 400000);
  bme.begin(0x76);
}

void loop() {
  do {
    active_time = millis() - millis_start;  // calculate wifi active time
    bool state_changed = false;

    switch (curr_state) {
      case STATE_SENSOR_INIT:
        if (bme.init())  // success
        {
          curr_state = STATE_SENSOR_READ;
          state_changed = true;

          custom_println("BME280 found");
          break;
        } else {
          custom_println("Retrying BME init...");
          vTaskDelay(BME_WAIT_MS);
        }
        break;

      case STATE_SENSOR_READ:
        bme.setSampling(Adafruit_BME280::MODE_FORCED,
                        Adafruit_BME280::SAMPLING_X1,  // temperature
                        Adafruit_BME280::SAMPLING_X1,  // pressure
                        Adafruit_BME280::SAMPLING_X1,  // humidity
                        Adafruit_BME280::FILTER_OFF);

        if (bme.takeForcedMeasurement()) {
          curr_state = STATE_NETWORK_INIT;
          state_changed = true;

          temp = bme.readTemperature();
          press = bme.readPressure() / 100.0F;
          humi = bme.readHumidity();

          custom_println("Sensor read done");
          break;
        } else {
          custom_println("Retrying measurement...");
          vTaskDelay(BME_WAIT_MS);
        }
        break;

      case STATE_NETWORK_INIT:  //Connect to the network
#if WIFI_USED == 1
        connectToWiFi(networkName, networkPswd);
#else
        SPI.begin(RF96_CLK, RF96_MISO, RF96_MOSI, RF96_CS);
        LoRa.setPins(RF96_CS, -1, RF96_DIO0);
        LoRa.setSPIFrequency(1E6);
        lora_active = true;
#endif  // WIFI_USED

        curr_state = STATE_NETWORK_WAIT;
        state_changed = true;
        break;


      case STATE_NETWORK_WAIT:
#if WIFI_USED == 0
        if (LoRa.begin(433E6)) {
          curr_state = STATE_SEND;
          state_changed = true;
        } else
#endif  // WIFI_USED
          vTaskDelay(NETWORK_WAIT_MS);

        break;

      case STATE_SEND:  //Send a packet
        {
          /* Approximate length in worst case:
         * 6 keys with quotation marks, colon         = 6 * 4   = 24
         * 5 comma separators                         = 5 * 1   =  5
         * 2 floats with 3 digits + point + 2 digits  = 2 * 6   = 12
         * 1 float with 2 digits + point + 2 digits   = 1 * 5   =  5
         * 1 float with 1 digits + point + 2 digits   = 1 * 4   =  4
         * 1 float with 4 digits + point + 0 digits   = 1 * 5   =  5
         * 2 integers with 10 digits max              = 2 * 10  = 20
         * terminator                                 = 1 * 1   =  1
         *
         * sum                                                  = 76
         * 
         * some padding :-) for furture use -> 256
         */
          char txBuffer[256];
          state_changed = true;

          // move data into buffer for sending and possible later evaluation
          size_t length = snprintf(txBuffer, sizeof(txBuffer),
                                   "{\"T\":%2.2f,\"P\":%3.2f,\"H\":%3.2f,\"L\":%lu,\"B\":%1.2f,\"D\":%lu,\"V\":%4.0f}",
                                   temp,
                                   press,
                                   humi,
                                   last_active,
                                   supercap_voltage,
                                   timeToSleepSeconds,
                                   last_delta_v);

#if WIFI_USED == 1
          /* hand over to network stack */
          Udp.begin(udpListenPort);
          Udp.beginPacket(udpAddress, udpSendPort);
          Udp.printf("%s", txBuffer);
          Udp.endPacket();
          curr_state = STATE_WAIT_ACK;
#else
          // Change sync word (0xF3) to match the receiver
          // The sync word assures you don't get LoRa messages from other LoRa transceivers
          // ranges from 0-0xFF
          LoRa.setSyncWord(0xAB);
          LoRa.beginPacket();
          LoRa.write((uint8_t*)txBuffer, length);
          LoRa.endPacket();
          curr_state = STATE_SLEEP;
#endif  // WIFI_USED

          /* Print message contents for simple debugging */
          custom_println("Sent: %s", txBuffer);
          break;
        }
      case STATE_WAIT_ACK:
#if WIFI_USED == 1
        if (Udp.parsePacket())  // received something
        {
          char packetBuffer[32];  // use some task stack to buffer message
          int len = Udp.read(packetBuffer, sizeof(packetBuffer));

          if (len > 0)  // set null terminator
          {
            packetBuffer[len] = 0;
          }

          /* Parse received contents of server here, if desired */
          custom_println("Received contents: %s", packetBuffer);

          curr_state = STATE_SLEEP;
          state_changed = true;
        } else {
          vTaskDelay(NETWORK_WAIT_MS);
        }
#endif  // WIFI_USED
        break;

      default:
        curr_state = STATE_SLEEP;
        state_changed = true;
        break;
    }

    if (state_changed) {
      custom_println("Active time: %lu, CPU freq: %lu", active_time, esp_clk_cpu_freq());
    }

    if (curr_state == STATE_SLEEP) {
      break;
    }

  } while (active_time < MAX_WAKEUP_MS);

  if (lora_active) // make sure to set transceiver into sleep in any case
    LoRa.sleep();

  /* Come here if either success or if timed out */
  last_delta_v = (supercap_voltage - measure_adc()) * 1000;  // calculate how much voltage dropped during operation
  custom_println("mV consumed: %f", last_delta_v);

  /* Prepare to sleep again */
  enter_deepsleep();
}

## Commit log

2023-05-17 Added basic project files
    [SunSparkESP32.kicad_pcb, SunSparkESP32.kicad_sch]
2023-05-19 Reworked placement of components Added low side switch instead of complicated high side IC Enhanced readme
    [SunSparkESP32.kicad_pcb, SunSparkESP32.kicad_sch]
2023-05-20 Minor enhancements to PCB Added BOM and PDF output
    [SunSparkESP32.kicad_pcb, SunSparkESP32_BOM.csv]
2023-05-22 Added optional footprint for RF95/96/97/98 footprint
    [SunSparkESP32.kicad_pcb, SunSparkESP32.kicad_sch]
2023-05-24 Rework due to first review -Replaced electrolytic caps with low ESR ceramic ones -Routing optimizations Also added possible connection for backup battery Routed some DIOs from LoRa module on controll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
    [SunSparkESP32.kicad_pcb, SunSparkESP32.kicad_sch, SunSparkESP32_BOM.csv]
2023-05-27 Finalized last review points, enhanced doc -Added Diode to prevent discharge from supercap into LDO -Updated BOM -Made readme nicer
    [SunSparkESP32.kicad_pcb, SunSparkESP32.kicad_sch, SunSparkESP32_BOM.csv]
2023-05-27 Last preparations for V2 board -Generated gerber + drill files for production -Updated PDF schematic output
    [SunSparkESP32-B_Cu.gbr, SunSparkESP32-B_Mask.gbr, SunSparkESP32-B_Paste.gbr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]
2023-05-27 Added Routing for DIO pins of modem
    [SunSparkESP32.kicad_pcb, SunSparkESP32.kicad_sch]
2023-05-28 place hole to pass checks
    [SunSparkESP32.kicad_pcb]
2023-05-28 Updated fabrication + schematic output due to additional DIO routing
    [SunSparkESP32-B_Cu.gbr, SunSparkESP32-B_Mask.gbr, SunSparkESP32-B_Paste.gbr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]
2023-05-28 Removed some ERC warnings -Added NC flag to non connected pins Remapped some DIOs to actual RTC GPIOs, so that external interrupts in deep sleep are possible
    [SunSparkESP32.kicad_pcb, SunSparkESP32.kicad_sch]
2023-06-17 Various fixes due to V2 testing -GPIO46 now not routed to external pin header -Corrected some silk -Cleaned up schematic
    [SunSparkESP32.kicad_pcb, SunSparkESP32.kicad_sch]
2023-06-27 Removed some debugging connectors -Directly connected backup supply -Removed series connector to supercap
    [SunSparkESP32.kicad_pcb, SunSparkESP32.kicad_sch]
2023-07-03 Minor improvements on documentation
    [SunSparkESP32.kicad_pcb, SunSparkESP32.kicad_sch]
2023-07-15 Final adjustments for release preparation -Updated schematics, BOM and fabrication files -Added solder jumper so RFM96 can be powered independently
    [SunSparkESP32-B_Cu.gbr, SunSparkESP32-B_Mask.gbr, SunSparkESP32-B_Paste.gbr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]
2023-07-16 Added SW template for utilization as wifi sensor node
    Enhanced documentation, cleaned up
    Provided code for BME280, but can also be used with other sensors
    Note: Altered Adafruit_BME280::begin so that is does NOT call
    Adafruit_BME280::init upon each wakeup of device -> sensor is permanently
    supplied with VCC and does not need a lengthy re-init each time
2023-09-26 Fixed new pinning, added pulldown for debug option
    [WiFiUDPClient.ino]
2023-09-29 connected RF96 pin to µC instead of reset button
    [SunSparkESP32.kicad_pcb, SunSparkESP32.kicad_sch]
2023-10-01 Added compile switch for using wifi or RF96 module
2023-10-11 Added housing and updated documentation
    [lid_small.stl]
